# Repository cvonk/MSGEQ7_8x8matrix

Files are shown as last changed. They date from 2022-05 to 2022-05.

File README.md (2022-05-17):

# MSGEQ7 8x8matrix





Spectrum analyzer display using MSGEQ7, 8x8 bicolor matrix and Arduino Uno. Input is from a head phone jack or microphone.

## Demo

Short but powerful.

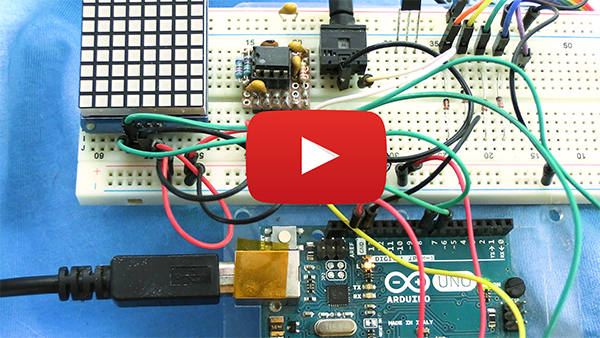
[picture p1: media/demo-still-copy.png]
demo_video (https://www.youtube.com/watch?v=W37uoCdih54&ab_channel=CoertVonk)


## Clone

Clone the repository and its submodules to a local directory. The `--recursive` flag automatically initializes and updates the submodules in the repository.

```bash
git clone --recursive https://github.com/cvonk/MSGEQ7_8x8matrix.git
```

or using `ssh`
```bash
git clone --recursive git@github.com:cvonk/MSGEQ7_8x8matrix.git
```

## Hardware

This project uses input from headphone input or amplified microphone and outputs to a 8x8 bicolor matrix.

### Schematic

Power

Schematic

Logic

Schematic

A few notes:
- The 200 kΩ resistor is not an E12-series value. You can also make an equivalent value by 220 kΩ and 2.2 MΩ in parallel, or put two 100 kΩ in series.
- If there is noise, try adding a 47 μF across the power rail.
- I put the MSGEQ7 and its glue on a piece of proto board.  
  

### Bill of materials

Make sure the MSGEQ7 is authentic. It should draw about \(0.8\,\rm{mA}\); pin 6 should have a reference voltage of about \(2.5\,\rm{V}\) and have an indentation near pin 1.

| Name | Description | Suggested mfr and part# | Paid |
|---|---|---|-----:|
| PCB1 | Arduino Uno R3 or compatible | Adafruit 2488 | [$17.50](https://www.adafruit.com/product/2488)
| PCB2 | Bicolor LED Square Pixel Matrix w/ I2C breakout | Adafruit 902 | [$15.95](https://www.adafruit.com/product/902)
| PCB3 | Electret microphone w/ auto gain control | Adafruit 1713 | [$7.95](https://www.adafruit.com/product/1713)
| U1 | Seven Band Graphic Equalizer Display Filter | MSI MSGEQ7 | [$5.50](https://www.digikey.com/en/products/detail/sparkfun-electronics/COM-10468/5806591)
| J1 | Headphone jack stereo connector, 3.5mm, kinked pin | Kycon STX-3120-5B | [$0.74](https://www.digikey.com/en/products/detail/kycon-inc/STX-3120-5B/9990114)
| R1, R2 | Resistor, 22 kOhm, 1%, 1/8 W, 0805 | Yageo RC0805FR-0722KL | [$0.10](https://www.digikey.com/en/products/detail/yageo/RC0805FR-0722KL/727736)
| R3 | Resistor, 200 kOhm, 1%, 1/8 W, 0805 | Yageo RC0805FR-07200KL | [$0.10](https://www.digikey.com/en/products/detail/yageo/RC0805FR-07200KL/7277240)
| C1, C2, C3 | Ceramic capacitor, 0.1 µF, 25V, 0805 | KEMET C0805C104M3RACTU | [$0.10](https://www.digikey.com/en/products/detail/kemet/C0805C104M3RAC7800/2211748)
| C4 | Ceramic capacitor, 33 pF, 50V, 0805 | KEMET C0805C330J5GAC7800 | [$0.10](https://www.digikey.com/en/products/detail/kemet/C0805C330J5GAC7800/411114)

### Notes

The popular Arduino UNO R3 forms the heart of the system. This board is now getting hard to find, but you can also use the Arduino METRO 328 or any other equivalent boards.

For the microphone, I use the Adafruit microphone breakout, because includes an automatic gain control. Other microphones will work for as long as the output signal is strong enough.

## Software

The implementation changes the sound wave to an electrical signal; uses autocorrelation to find frequency played; display frequency as note on screen while sending to a MIDI synthesizer.

### Requirements

| Component | Version tested |
|---|---|
| Arduino IDE | 1.8.19
| Arduino AVR Boards | 1.8.5
| Adafruit LED Backpack library | 1.3.2
| Adafruit GFX library | 1.11.1

### Build

- Install the libraries.
- Using the Arduino IDE or Visual Code
    - Specify the board and COM port.
    - Build and upload the sketch .

## Details

The [MSI MSGEQ7](http://www.mix-sig.com/images/datasheets/MSGEQ7.pdf) measures the peak voltage in 7 frequency bands. These voltages are multiplexed on one output pin. The timing is shown below, and includes some corrections compared to the datasheet [Maxfield](http://www.eetimes.com/author.asp?doc_id=1323030).

timing

To read each value, we use the `RESET` and `STROBE*` pins.
  - A `RESET` pulse followed by a wait (≥72 μs) resets the multiplexer.
  - On the first falling edge of the strobe signal, the 63 Hz band output propagates to `OUT`. After ≥36 μs, this analog value can be read by the host.
  - Each additional strobe falling edge advances the multiplexer one frequency band (63 &raquo; 160 &raquo; 400 &raquo; 1,000 &raquo; 2,500 &raquo; 6,250 &raquo; 16,000 Hz) and this will repeat indefinitely.

> Each read operation decays the value of that frequency band by approximately 10%. This means that if the Arduino reads less often, e.g. as a result of doing computations, the values read will be higher.

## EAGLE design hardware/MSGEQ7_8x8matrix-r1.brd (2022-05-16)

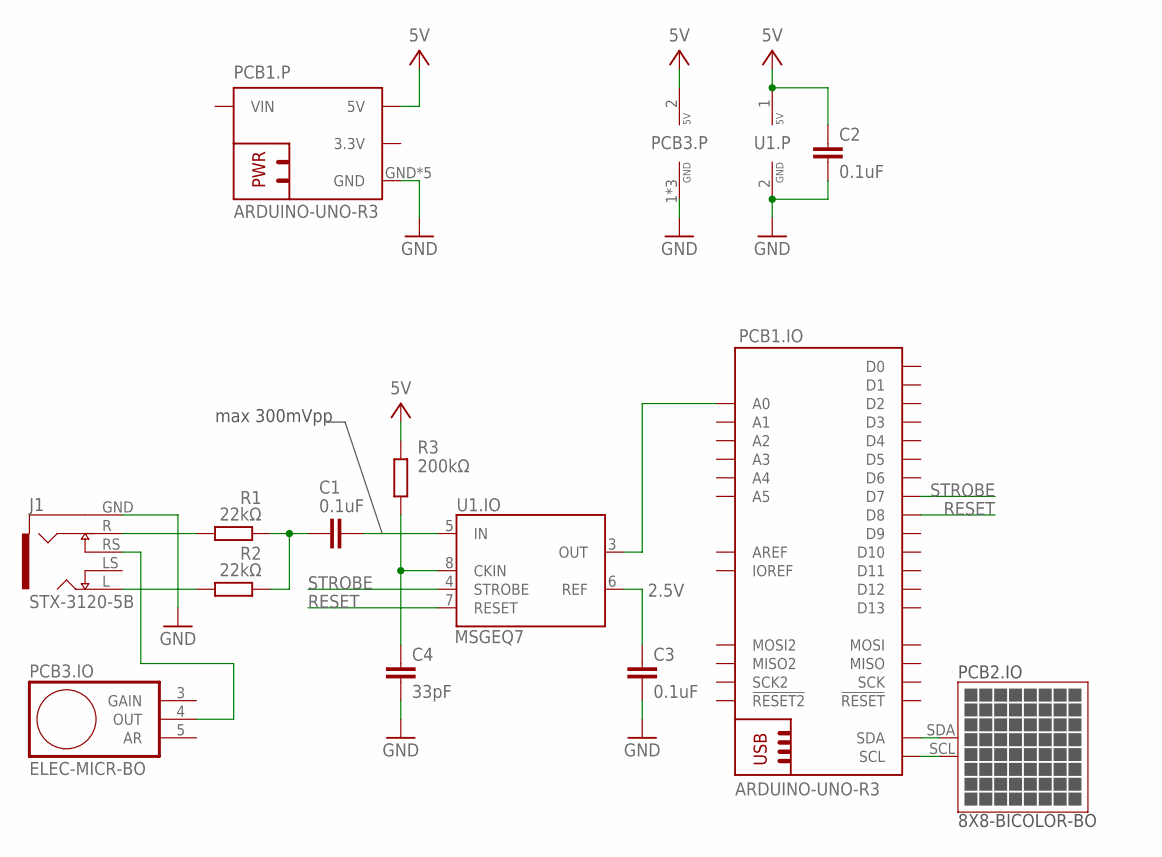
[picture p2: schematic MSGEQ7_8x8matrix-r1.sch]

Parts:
C1, C2, C3: 0.1uF; C0805K; MOUSER# 81-GJ821BR61E106KE1L
C4: 33pF; C0805K; MOUSER# 81-GJ821BR61E106KE1L
J1: STX-3120-5B
PCB1: ARDUINO-UNO-R3; ARDUINO-UNO--R3
PCB2: ADAFRUIT-8X8LED-BO; ADAFRUIT-8X8LED
PCB3: ELEC-MICR-BO; ELEC_MICR_BREAKOUT
R1, R2: 22kΩ; R0805; MOUSER# 652-CRM0805JW1R5ELF
R3: 200kΩ; R0805; MOUSER# 652-CRM0805JW1R5ELF
U1: MSGEQ7DIL; DIL-08

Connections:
2.5V: C3.1, U1.6 (REF)
5V: C2.1, PCB1.5V, PCB1.5V@1 (5V), PCB1.5V@2 (5V), PCB3.2 (5V), R3.1, U1.1 (5V)
GND: C2.2, C3.2, C4.2, J1.GND (1), PCB1.GND, PCB1.GND@1 (GND), PCB1.GND@2 (GND), PCB1.GND@3 (GND), PCB1.GND@4 (GND), PCB3.1 (GND), PCB3.P$1 (GND), PCB3.P$2 (GND), U1.2 (GND)
unnamed: J1.R (3), R1.2
unnamed: C1.1, R1.1, R2.1
unnamed: C1.2, U1.5 (IN)
unnamed: J1.L (2), R2.2
unnamed: PCB1.SDA, PCB2.SDA
unnamed: C4.1, R3.2, U1.8 (CKIN)
unnamed: PCB1.A0, U1.3 (OUT)
unnamed: J1.RS (11), PCB3.4 (OUT)
unnamed: PCB1.SCL, PCB2.SCL
RESET: PCB1.D8, U1.7 (RESET)
STROBE: PCB1.D7, U1.4 (STROBE)

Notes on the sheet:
max 300mVpp

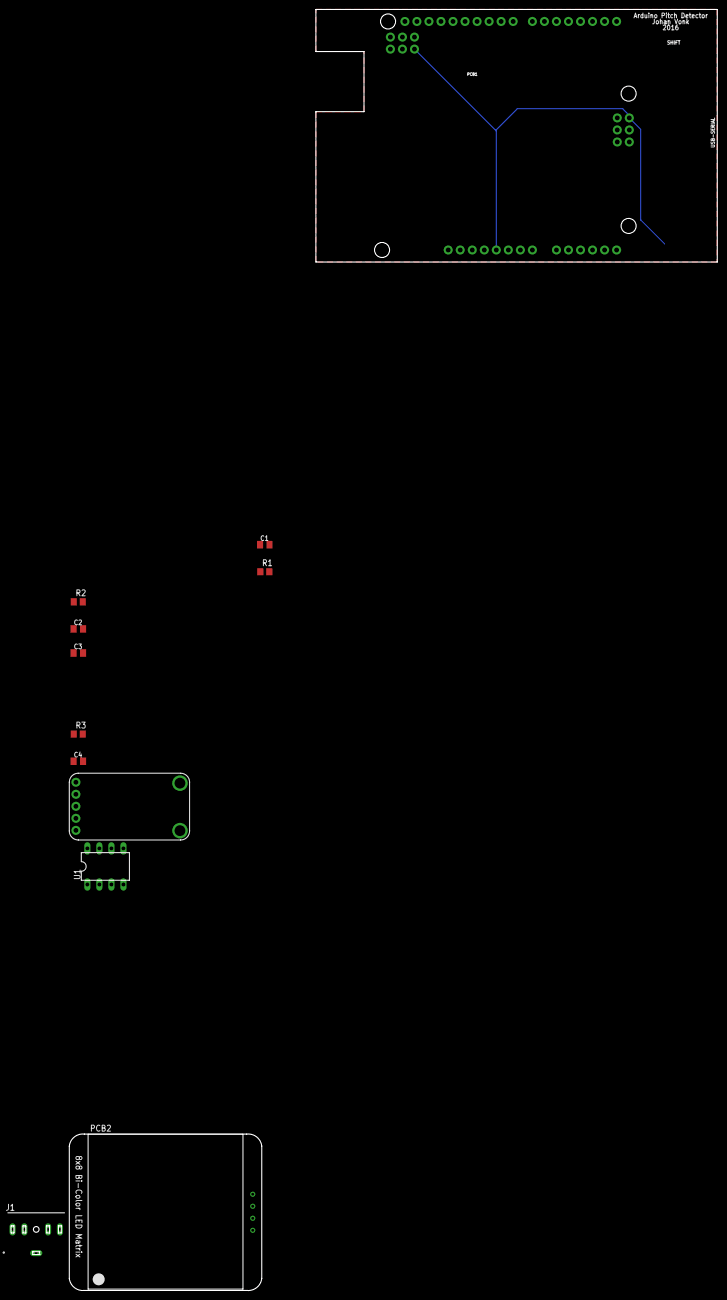
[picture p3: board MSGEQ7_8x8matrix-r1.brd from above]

Board: 2 copper layers, 149.1 x 270.5 mm, 12 parts (0 on the bottom side), 14 nets.

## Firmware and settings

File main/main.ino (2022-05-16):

/**
 * @file main.ino
 * @author Coert Vonk
 * @brief Spectrum analyzer display using MSGEQ7, 8x8 bicolor matrix and Arduino Uno. (https://github.com/cvonk/MSGEQ7_8x8matrix)
 * @version 1.0
 * @date 2022-05-16
 * 
 * For testing, use https://www.szynalski.com/tone-generator/
 * 
 * @copyright Copyright (c) 2022
 * 
 */
#include <Arduino.h>
#include <Wire.h>
#include <Adafruit_GFX.h>  // git@github.com:adafruit/Adafruit-GFX-Library.git
#include <Adafruit_LEDBackpack.h>  // git@github.com:adafruit/Adafruit_LED_Backpack.git

#define STROBE_PIN (7)
#define RESET_PIN (8)
#define ANALOG_PIN (0)

typedef uint8_t sample_t;
#define MSGEQ7_CHANNEL_CNT (7)

void
_update_matrix(Adafruit_BicolorMatrix * matrix, sample_t const * const spectrum)
{
    static sample_t peak[MSGEQ7_CHANNEL_CNT + 1] = {}; // peak level of each column
    static uint_least8_t dotCount = 0;

    matrix->clear();
    matrix->fillRect(0, 0, 3, MSGEQ7_CHANNEL_CNT, LED_GREEN);  // bottom 3 LEDs are green
    matrix->fillRect(3, 0, 2, MSGEQ7_CHANNEL_CNT, LED_YELLOW); // middle 2 LEDs are yellow
    matrix->fillRect(5, 0, 3, MSGEQ7_CHANNEL_CNT, LED_RED);    // top 3 LEDs are red

    for (int xx = 0; xx < MSGEQ7_CHANNEL_CNT; xx++) {

        if (spectrum[xx] > peak[xx]) {  // mark peak
            peak[xx] = spectrum[xx];
        }

        if (peak[xx] == 0) {
            matrix->drawLine(0, xx, 7, xx, LED_OFF);
            continue;
        }
        if (spectrum[xx] < 7) {
            matrix->drawLine(spectrum[xx], xx, 7, xx, LED_OFF);
        }

        matrix->drawPixel(peak[xx] - 1, xx, peak[xx] - 1 < 3 ? LED_GREEN : 
                                                  peak[xx] - 1 < 5 ? LED_YELLOW : LED_RED);
    }
    matrix->writeDisplay();

    // make the peak pixels drop
    if (++dotCount >= 50) {
        dotCount = 0;
        for (uint_least8_t xx = 0; xx < MSGEQ7_CHANNEL_CNT; xx++) {
            if (peak[xx] > 0) peak[xx]--;
        }
    }
}

namespace {
    Adafruit_BicolorMatrix * _matrix;
}

void setup() 
{
    Serial.begin(9600);

    _matrix = new Adafruit_BicolorMatrix();
    _matrix->begin(0x70);

    pinMode(RESET_PIN, OUTPUT);
    pinMode(STROBE_PIN, OUTPUT);
}

void loop() 
{
    digitalWrite(RESET_PIN, HIGH); // reset the MSGEQ7's counter
    delay(5);
    digitalWrite(RESET_PIN, LOW);

    sample_t samples[MSGEQ7_CHANNEL_CNT];

    for (int ii = 0; ii < MSGEQ7_CHANNEL_CNT; ii++){
        digitalWrite(STROBE_PIN, LOW); // output each DC value for each freq band
        delayMicroseconds(35); // to allow the output to settle
 
        int spectrumRead = analogRead(ANALOG_PIN);
        if (spectrumRead < 150) {
            spectrumRead /= 2;
        }
        samples[ii] = map(spectrumRead, 0, 950, 0, 8);  // scale to [0..8]
        digitalWrite(STROBE_PIN, HIGH);
    }

    for (int ii = 0; ii < MSGEQ7_CHANNEL_CNT; ii++){
        _update_matrix(_matrix, samples);
    }
}
